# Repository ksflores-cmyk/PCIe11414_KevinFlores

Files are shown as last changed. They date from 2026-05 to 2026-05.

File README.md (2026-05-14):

# Proyecto Final de Electrónica 2 y Diseño Electrónico 1 - PCIe11414 NIC 

<div align="center">
  <em>Universidad del Istmo de Guatemala</em><br>
  <em>Facultad de Ingeniería</em><br>
  <em>Proyecto Final</em><br>
  <em>Electrónica 2 y Diseño Electrónico 1</em>

  <br><br>

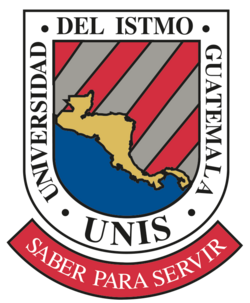
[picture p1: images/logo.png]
Logo UNIS
  
  
  <br><br>

  <em>Kevin Flores</em><br>
  <em>Mayo de 2026</em>
</div>

##  Descripción General
Este repositorio contiene el diseño a nivel de hardware de una tarjeta de red (NIC) con conexión PCIe. Desarrollado íntegramente en OrCAD, el proyecto documenta el proceso de ingeniería que incluye la selección de componentes, el diseño del esquemático y el layout de la PCB. Se prestó especial atención al enrutamiento de señales diferenciales y al cumplimiento de los estándares físicos que requiere el protocolo PCI Express.

##  Objetivos
* **Principal:** Diseñar a nivel de hardware (captura esquemática y layout de PCB) una Tarjeta de Interfaz de Red (NIC) y Hub basada en el switch PCI Express **PCI11414**, utilizando la suite de OrCAD y cumpliendo con los requerimientos técnicos del curso de Electrónica 2.
* **Específicos:**
  * Desarrollar el diagrama esquemático completo asegurando la interconexión entre el bus PCIe (Upstream x4), el switch PCI11414 y el transceptor Ethernet Gigabit (PHY) KSZ9131.
  * Implementar técnicas de diseño de placas de alta velocidad, incluyendo el ruteo de pares diferenciales y control de impedancia para el bus PCIe y las líneas de red.
  * Diseñar la red de distribución de energía (PDN) para adaptar los 12V de entrada a los voltajes de operación internos requeridos (5V, 3.3V, 2.5V y 1.1V).
  * Generar la documentación y los archivos de fabricación (Gerbers) correspondientes al diseño final.

##  Hardware y Componentes Utilizados
El diseño se basó en el esquemático de referencia de la tarjeta de evaluación EVB-PCI11414 de Microchip, utilizando componentes de montaje superficial (SMD) enfocados en telecomunicaciones de alta velocidad. A continuación, se detallan los componentes clave:

**Software de Diseño:**
* **Cadence OrCAD Capture:** Para la creación y jerarquización del diagrama esquemático.
    <br>
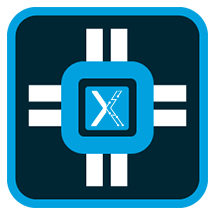
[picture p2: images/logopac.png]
Cadence OrCAD Capture
  
  <br><br>
* **Cadence Allegro PCB Editor:** Para el ruteo de pistas, manejo de capas y generación del layout.
    <br>
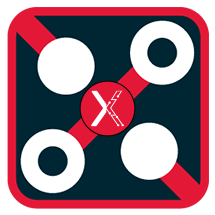
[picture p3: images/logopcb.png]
Cadence Allegro PCB Editor
  
  <br><br>

**Componentes Principales del Diseño:**
* **Switch PCIe Principal:** Microchip **PCI11414** (PCIe Switch con soporte para USB Host, Quad-UART y puerto Ethernet).
* **Controlador Ethernet (PHY):** Microchip **KSZ9131** (Transceptor Gigabit Ethernet 10/100/1000Base-T).
* **Interfaces de Bus PCIe:** * Conector tipo "Edge" PCI Express x4 (Upstream / conexión a la placa base).
  * Conector de ranura PCI Express x1 (Downstream).
* **Conector de Red:** Jack RJ45 modular con transformadores de aislamiento magnético integrados y LEDs indicadores.
* **Gestión de Energía:** Red de reguladores de voltaje tipo Buck y LDO (ej. Módulos PM8/LV2 y OKR-T) para reducir los 12V principales a rieles de 5V, 3.3V, 2.5V y 1.1V.
* **Sincronización (Relojes):** Cristal oscilador principal de 25 MHz (VXM7) y un Buffer de reloj de referencia PCIe de 2 canales (Microchip ZL40262LDF1).
* **Memoria de Configuración:** Memoria EEPROM I2C (AT24C64D) para almacenar la configuración de inicio del sistema.

## Diagrama de Bloques

A continuación se presenta la arquitectura general y el flujo de datos del diseño:

<div align="center">
<br>
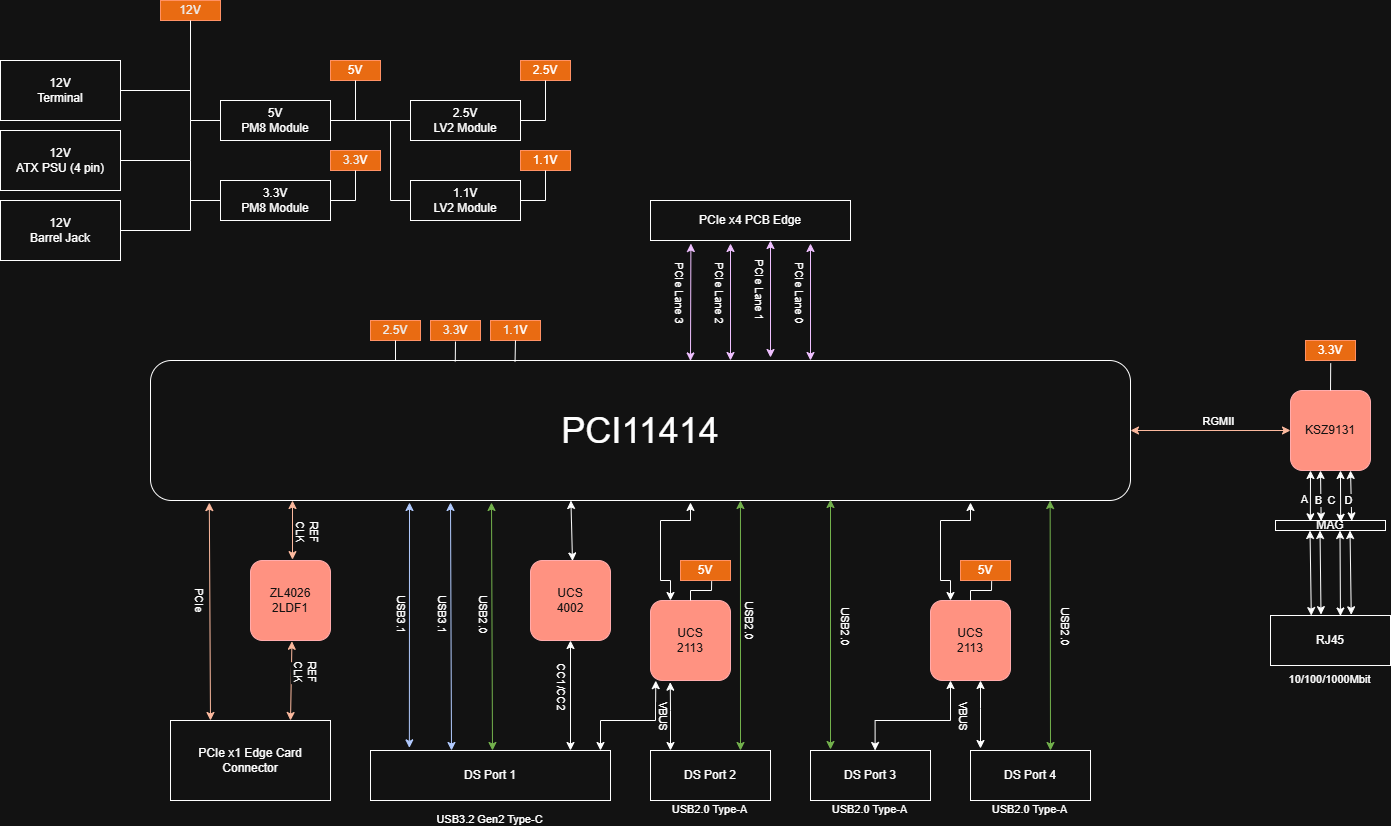
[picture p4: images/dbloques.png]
Diagrama de Bloques del Switch PCIe a NVMe
  
  
  <br>
  <em>Diagrama de bloques del sistema.</em>
</div>

##  Esquemáticos y Diseño
La arquitectura del circuito se fundamenta en el switch **PCI11414**, que funciona como el nodo central de comunicación. Este integrado gestiona el flujo de datos entre la interfaz **PCIe x4** de entrada (Upstream) y los diversos periféricos, incluyendo el controlador Ethernet **KSZ9131** y una ranura de expansión **PCIe x1** (Downstream).

Para garantizar la estabilidad del sistema, se implementó una arquitectura de potencia de cuatro etapas que regula la entrada principal de **12V** hacia los rieles de **5V**, **3.3V**, **2.5V** y **1.1V** requeridos por los distintos núcleos del switch y el PHY de red. La integridad de la señal se mantiene mediante un buffer de reloj especializado y un cristal de **25 MHz** para la sincronización de datos.
<div align="center">
<br><br>
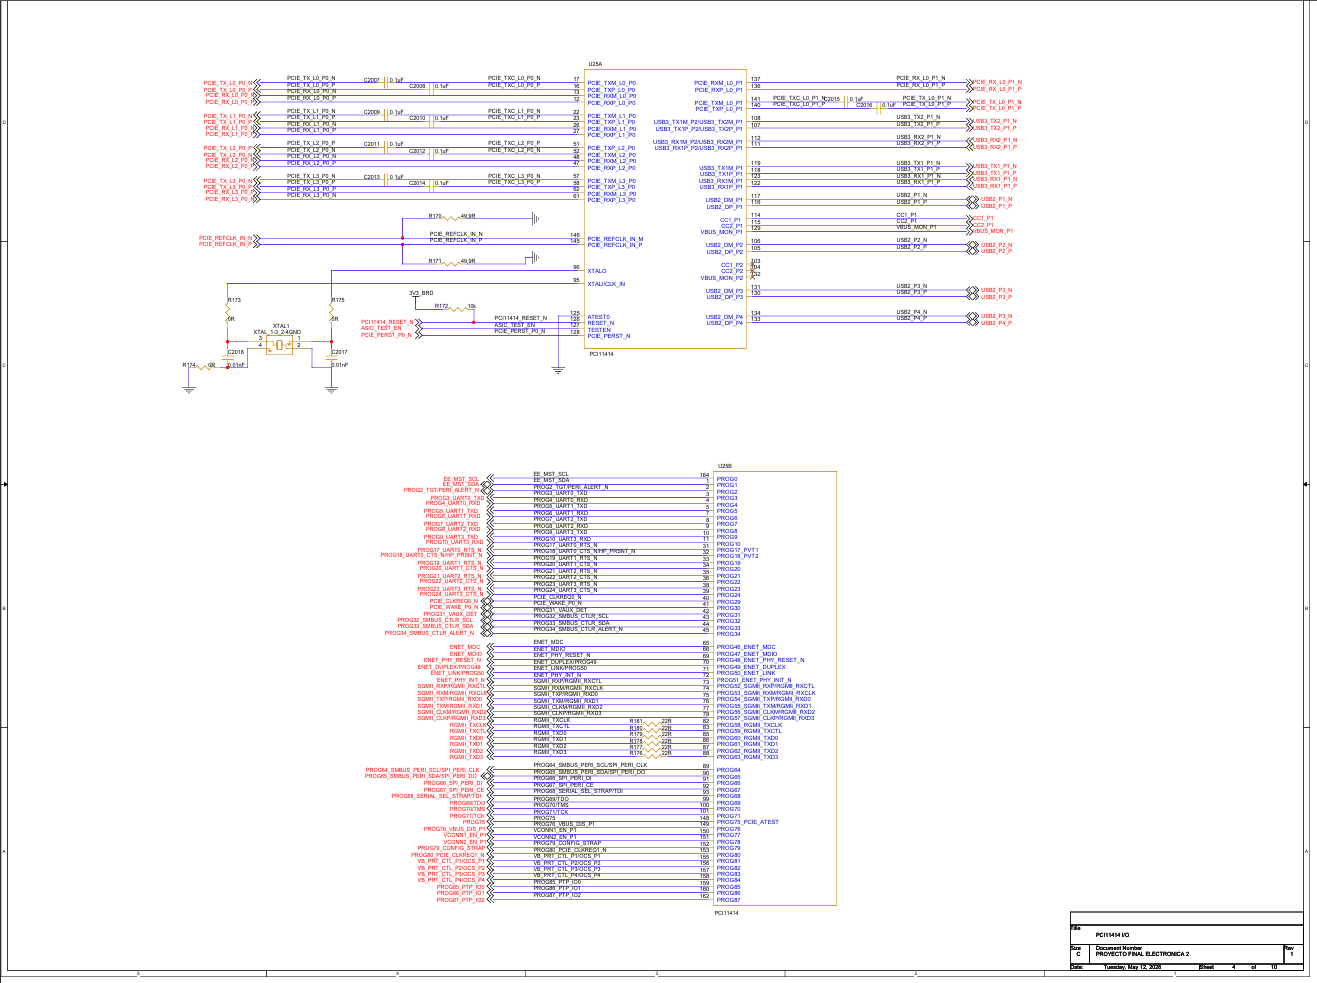
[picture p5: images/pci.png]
Esquemático de Conexiones - PCI11414
  
  
  <br>
  <em>Diagrama esquemático de conexiones para el IC PCI11414.</em>

<br><br>
> **Nota:** Todos los archivos técnicos, incluyendo las imágenes del esquemático completo y las capturas del diseño de la PCB, se encuentran disponibles en la carpeta `/[ESQUEMATICO]` de este repositorio.
 </div> 

##  Autor
Kevin Sebastian Flores López - Estudiante de Ingeniería Electrónica y Telecomunicaciones - https://github.com/ksflores-cmyk

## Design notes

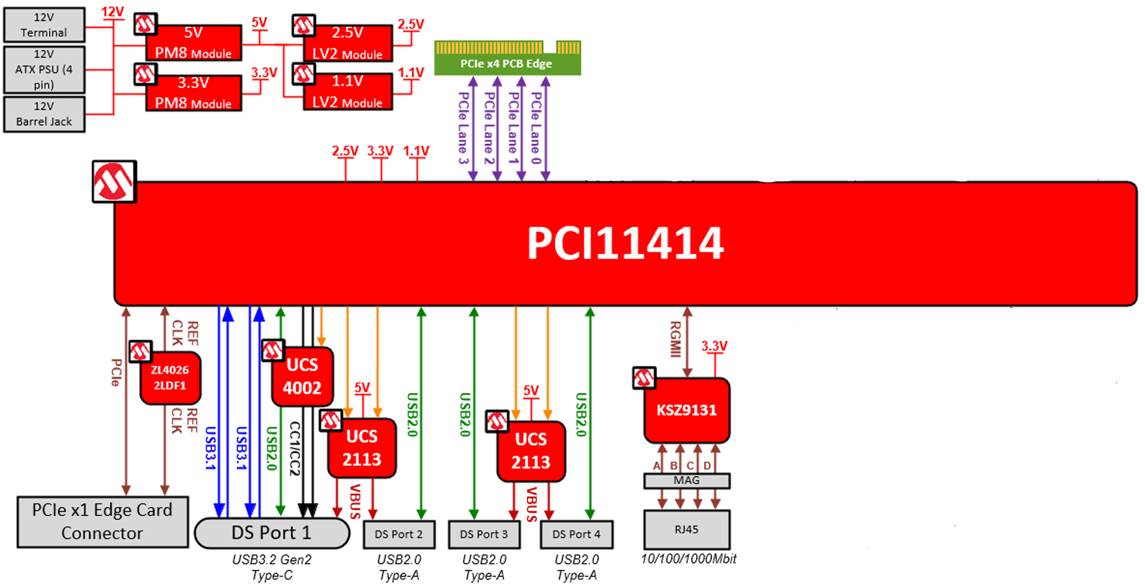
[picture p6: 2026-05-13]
images/Diagrama de Bloques.png

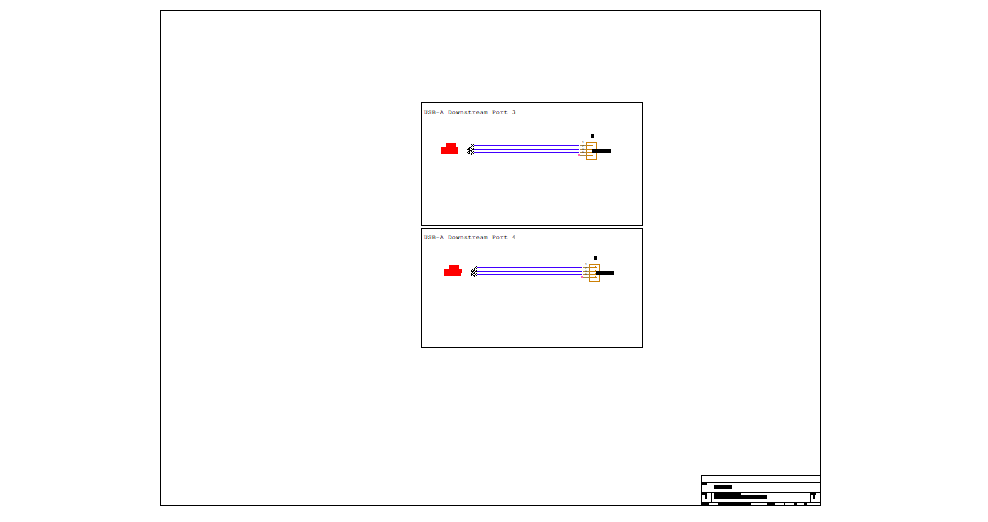
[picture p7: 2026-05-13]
DSN & BRD/PCI11414_KEVIN FLORES.png

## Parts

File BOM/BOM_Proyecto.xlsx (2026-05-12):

Capacitores (Desacople, Filtrado y Bulk) |  |  |  | Resistencias |  |  |  | Circuito Integrado
Categoría | Referencia | Valor | Voltaje / Encapsulado (Contexto) | Categoría | Referencia | Valor | Tolerancia / Observaciones | Categoría | Número de Parte / Referencia | Descripción | Cantidad
Capacitor Cerámico | C22, C31 | 4.7uF | 0603 (Desacople de potencia Ethernet PHY) | Resistencia | R221 | 43k | 1% (Divisor de voltaje VBUS) | Circuito Integrado | PCI11414 | Switch PCIe con host USB xHCI / Quad-UART / Ethernet | 1
Capacitor Cerámico | C23, C24, C40 | 0.1uF | 0603 (Desacople general) | Resistencia | R222 | 49.9k | 1% (Precisión para monitoreo) | Circuito Integrado | KSZ9131 | Ethernet PHY 10/100/1000MBit | 1
Capacitor Cerámico | C42 | 22uF | 10V / 0603 | Resistencia | R25, R88, R169 | 100k | Pull-up / Pull-down general | Circuito Integrado | ZL40262LDF1 | Buffer de Reloj PCIe (2 canales) | 1
Capacitor Cerámico | C200 | 47uF | 6.3V (Filtrado PMOS) | Resistencia | R149, R151, R233 | 10k | Configuración de pines (Strapping) | Circuito Integrado | AT24C64D | Memoria EEPROM I2C | 1
Capacitor Cerámico | C189, C191 | 22uF / 0.1uF | Filtrado entrada 12V PCIe | Resistencia | R40 | 20R | Resistencia en serie | Circuito Integrado | MAX3161 | Transceptor UART Multiprotocolo (RS-232/RS-485) | 4
Capacitor Cerámico | C83, C80 | 1000pF | Desacople de alta frecuencia (PCI11414) | Resistencia | R179, R165 | 330R | Limitadora de corriente para LEDs | Circuito Integrado | UCS4002 | Protección USB Type-C y fuente VCONN | 1
 |  |  |  | Resistencia | R6, R11, R7 | 22R | Terminación en serie para señales RGMII (Ethernet) | Circuito Integrado | UCS2113 | Switch de potencia para puertos USB | 2
 |  |  |  |  |  |  |  | Reloj / Oscilador | VXM7-9013-25M0000000 | Cristal de 25MHz | 1
 |  |  |  |  |  |  |  | Módulo de Potencia | OKR-T/6-W12 | Regulador DC-DC 12V a 5V/3.3V (6A) | -
 |  |  |  |  |  |  |  | Módulo de Potencia | PM-LV2 3.6V 3A | Regulador DC-DC para 2.5V y 1.1V | -
 |  |  |  |  |  |  |  | Módulo de Potencia | ADM00987 | Regulador LDO / Controlador | 1
 |  |  |  |  |  |  |  | Conector (Borde) | PCIe x4 PCB Edge | Conector de borde PCIe Upstream (hacia tarjeta madre) | 1
 |  |  |  |  |  |  |  | Conector (Slot) | PCIe x1 Edge Card | Slot PCIe Downstream | 1
 |  |  |  |  |  |  |  | Conector (Red) | RJ45 | Puerto Ethernet Gigabit (con magnéticos) | 1
 |  |  |  |  |  |  |  | Conector (USB) | USB Type-C | Puerto USB 3.2 Gen2 Downstream | 1
 |  |  |  |  |  |  |  | Conector (USB) | USB Type-A | Puerto USB 2.0 Downstream | 3
 |  |  |  |  |  |  |  | Conector (Serial) | DE-9 (Macho) | Conector DB9 para puerto serial RS-232 | 4
 |  |  |  |  |  |  |  | Conector (Serial) | Header RS-485 | Conector de pines para RS-485 | 4
 |  |  |  |  |  |  |  | Conector (Poder) | 12V Terminal | Bloque de terminales 12V | 1
 |  |  |  |  |  |  |  | Conector (Poder) | ATX PSU (4 pin) | Conector de fuente de poder ATX 12V | 1
 |  |  |  |  |  |  |  | Conector (Poder) | 12V Barrel Jack | Conector cilíndrico estándar 12V | 1

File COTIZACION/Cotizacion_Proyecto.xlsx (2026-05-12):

Cotización y BOM Consolidado |  |  |  |  |  | Costos de Manufactura, Ensamble y Envío
Categoría | Número de Parte / Ref. | Descripción | Cant. | Precio Unit. Est. (USD) | Subtotal Est. (USD) | Concepto de JLCPCB | Descripción Técnica | Subtotal Estimado (USD)
Integrado (Switch PCIe) | PCI11414 | Switch PCIe con host USB xHCI / Quad-UART / Ethernet | 1 | $30.56 | $30.56 | Fabricación PCB Bareboard | 5 unidades. 4 Capas (Impedancia controlada). Acabado ENIG + Gold Fingers + Biselado (Edge connector 45°). Tamaño est. 100x100mm. | ~$45.00
Integrado (Red) | KSZ9131RNXC | Ethernet PHY 10/100/1000MBit | 1 | $4.14 | $4.14 | Tarifa de Setup PCBA | Cargo fijo de JLCPCB por preparar la máquina Pick & Place (Setup fee + Stencil). | ~$10.00
Integrado (Reloj) | ZL40262LDF1 | Buffer de Reloj PCIe (2 canales) | 1 | $3.50 | $3.50 | Mano de obra Ensamble (SMT) | Costo por punto de soldadura para ensamblar 2 unidades. | ~$15.00
Integrado (Memoria) | AT24C64D | Memoria EEPROM I2C | 1 | $0.17 | $0.17 | Envío a Guatemala | DHL Express o FedEx (Esencial. Tarda aprox. 5-7 días hábiles a GT). | ~$40.00
Integrado (UART) | MAX3161 | Transceptor UART (RS-232/RS-485) | 4 | $4.50 | $18.00 | SUBTOTAL MANUFACTURA |  | ~$110.00
Integrado (Prot. USB) | UCS4002 | Protección USB Type-C y fuente VCONN | 1 | $1.60 | $1.60
Integrado (Switch USB) | UCS2113-1C-V/G4 | Switch de potencia para puertos USB | 2 | $1.21 | $2.42
Reloj / Oscilador | VXM7-9013-25M... | Cristal de 25MHz | 1 | $0.50 | $0.50
Módulo DC-DC | OKR-T/6-W12 | Regulador 12V a 5V/3.3V (6A) | 1 | $5.00 | $5.00
Módulo DC-DC | PM-LV2 3.6V 3A | Regulador para 2.5V y 1.1V | 1 | $4.00 | $4.00
Regulador LDO | ADM00987 | Regulador / Controlador | 1 | $1.00 | $1.00
Conector (Upstream) | PCIe x4 PCB Edge | Conector de borde PCIe (Oro en PCB) | 1 | N/A (PCB) | $0.00
Conector (Downstream) | PCIe x1 Edge Card | Slot PCIe Hembra (SMT o THT) | 1 | $1.50 | $1.50
Conector (Red) | RJ45 | Puerto Ethernet Gigabit con magnéticos | 1 | $2.00 | $2.00
Conector (USB) | USB Type-C | Puerto USB 3.2 Gen2 | 1 | $0.80 | $0.80
Conector (USB) | USB Type-A | Puerto USB 2.0 | 3 | $0.40 | $1.20
Conector (Serial) | DE-9 (Macho) | Conector DB9 RS-232 | 4 | $0.60 | $2.40
Conector (Poder/Extra) | Headers / Terminales | RS-485, Jack 12V, ATX 4-pin, Terminal block | Lote | $3.00 | $3.00
Pasivos (SMD) | Varios | Capacitores, Resistencias, Ferritas, LEDs | Lote | $5.00 | $5.00
TOTAL ESTIMADO |  |  |  |  | ~$86.79 USD

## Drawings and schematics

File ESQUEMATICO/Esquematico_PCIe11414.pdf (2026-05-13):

5

4

3

2

1

D D

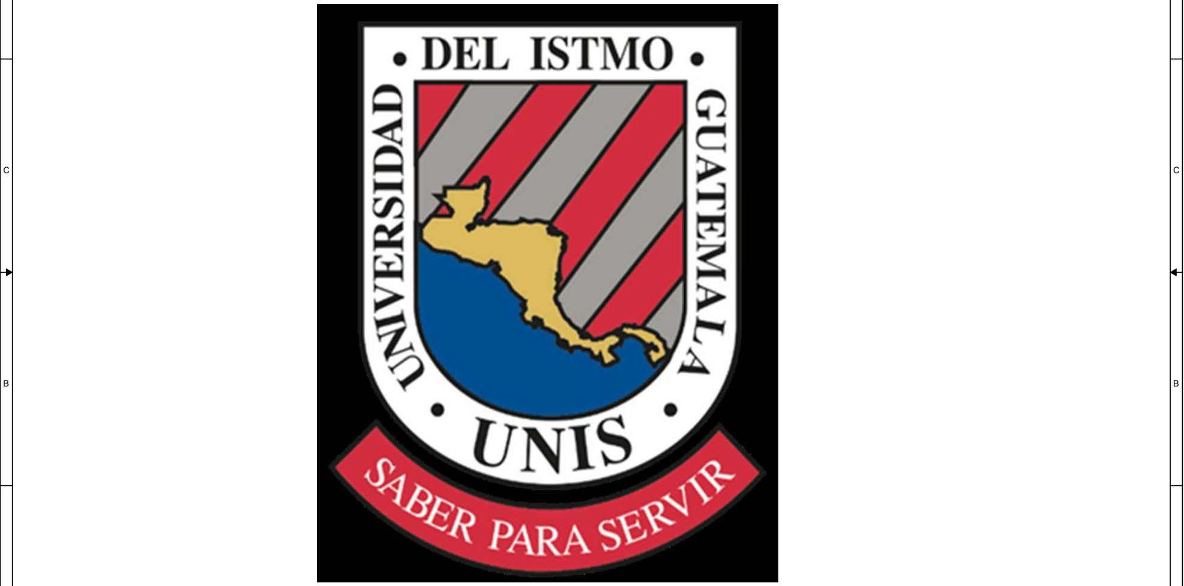
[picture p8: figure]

A A

# ABRIL DE 2026

# ELECTRONICA 2 Y DISENO ELECTRICO 1

# UNIVERSIDAD DEL ISTMO DE GUATEMALA FACULTAD DE INGENIERIA

# PROYECTO FINAL - PCIe NIC 11414

# KEVIN SEBASTIAN FLORES LOPEZ

D D

C C

B B

A A

# UPSTREAM PORT

# DOWNSTREAM SWITCH PORT

I/O

PG. #

# PCIe NVMe SWITCH - TABLE OF CONTENTS

5

# POWER

4

# BOARD POWER & RESETS

3

6

2

# SECTION

8

9

# ETHERNET

DOWNSTREAM PORTS | 7

# ETHERNET POWER

D D

# 12V - 5V Regulator

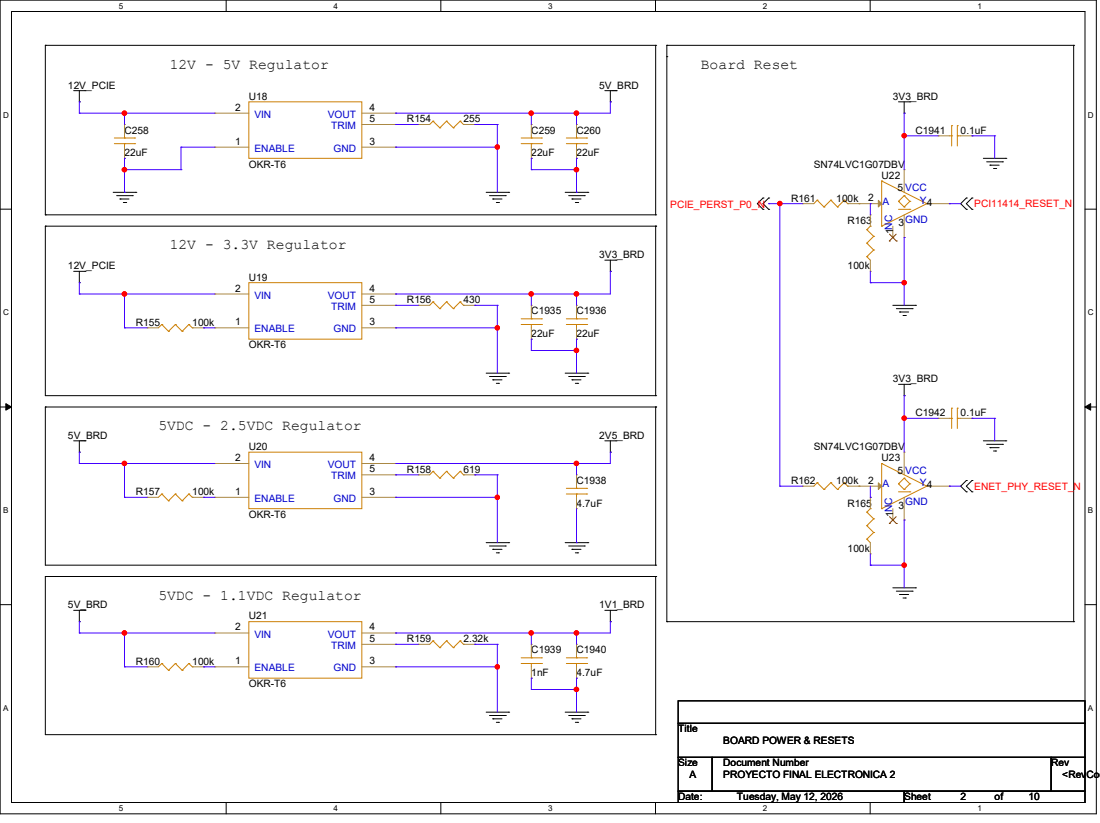
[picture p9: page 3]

### 2V5_BRD

### 3V3_BRD

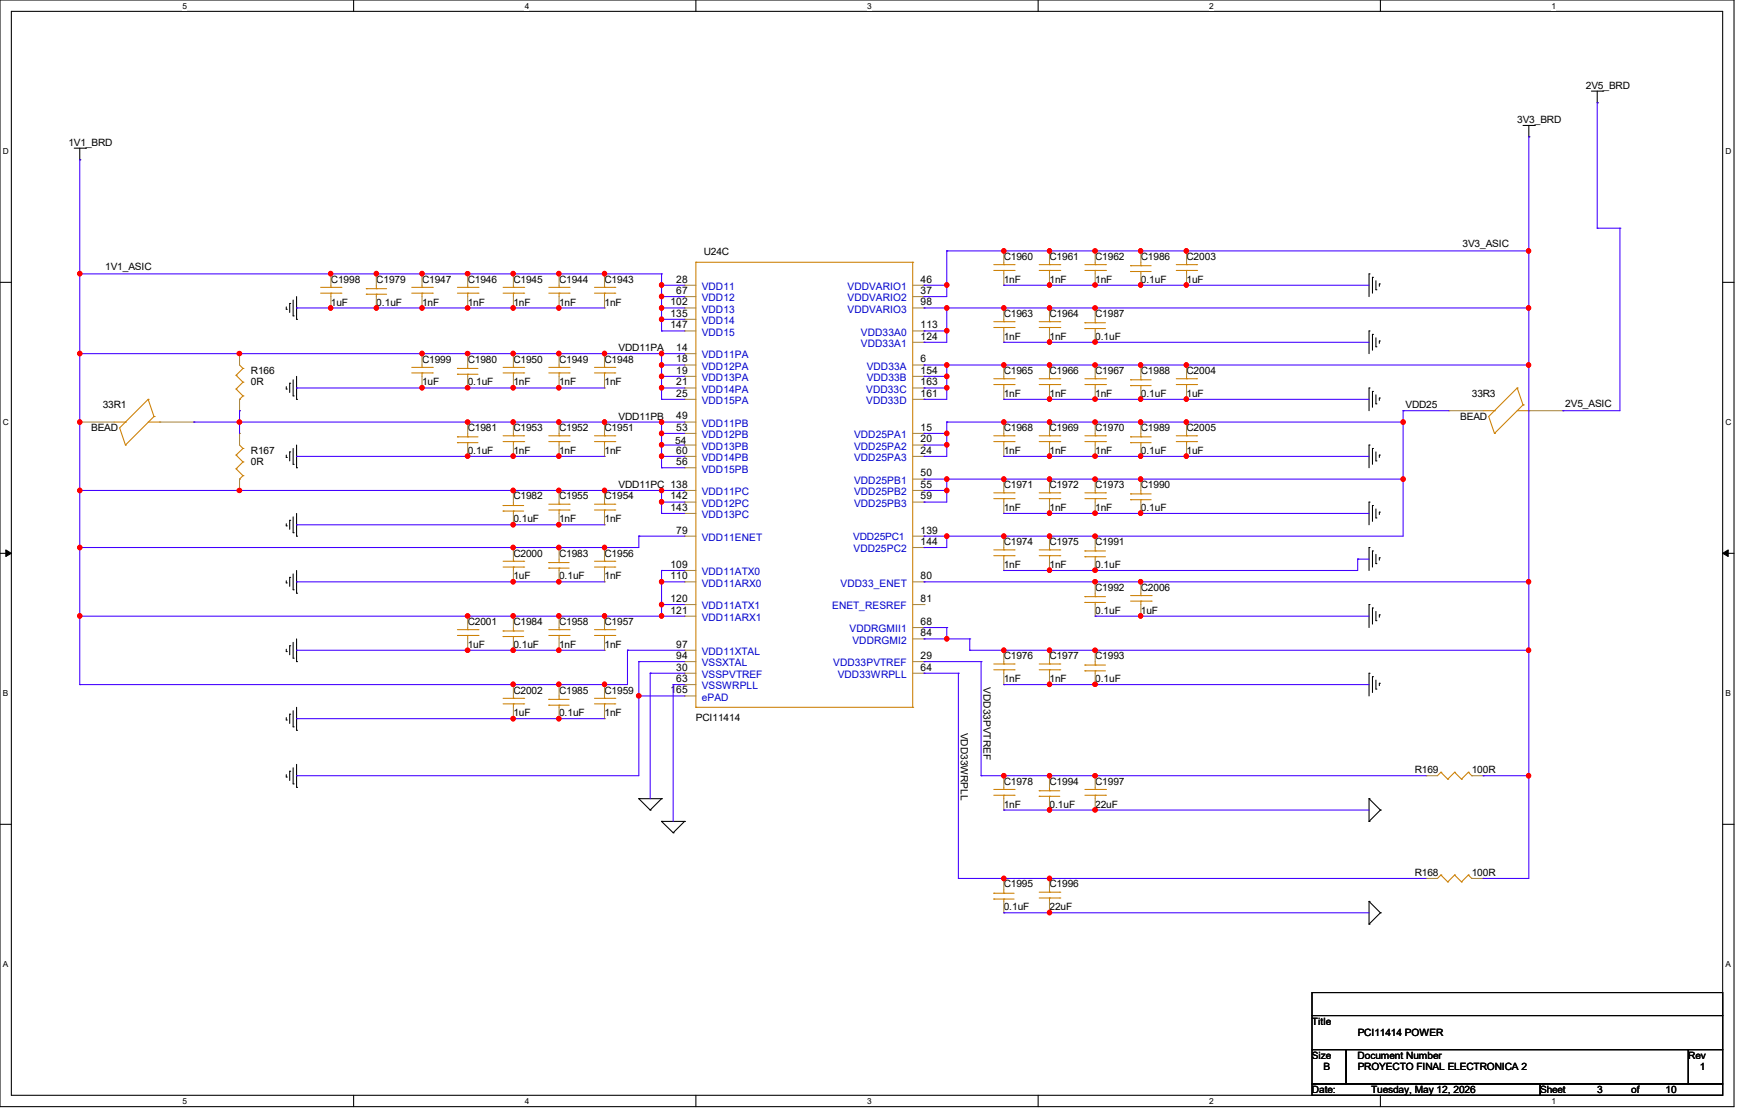
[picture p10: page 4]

# USB2_P4_P USB2_P1_N

# USB2_P1_P USB2_P3_P

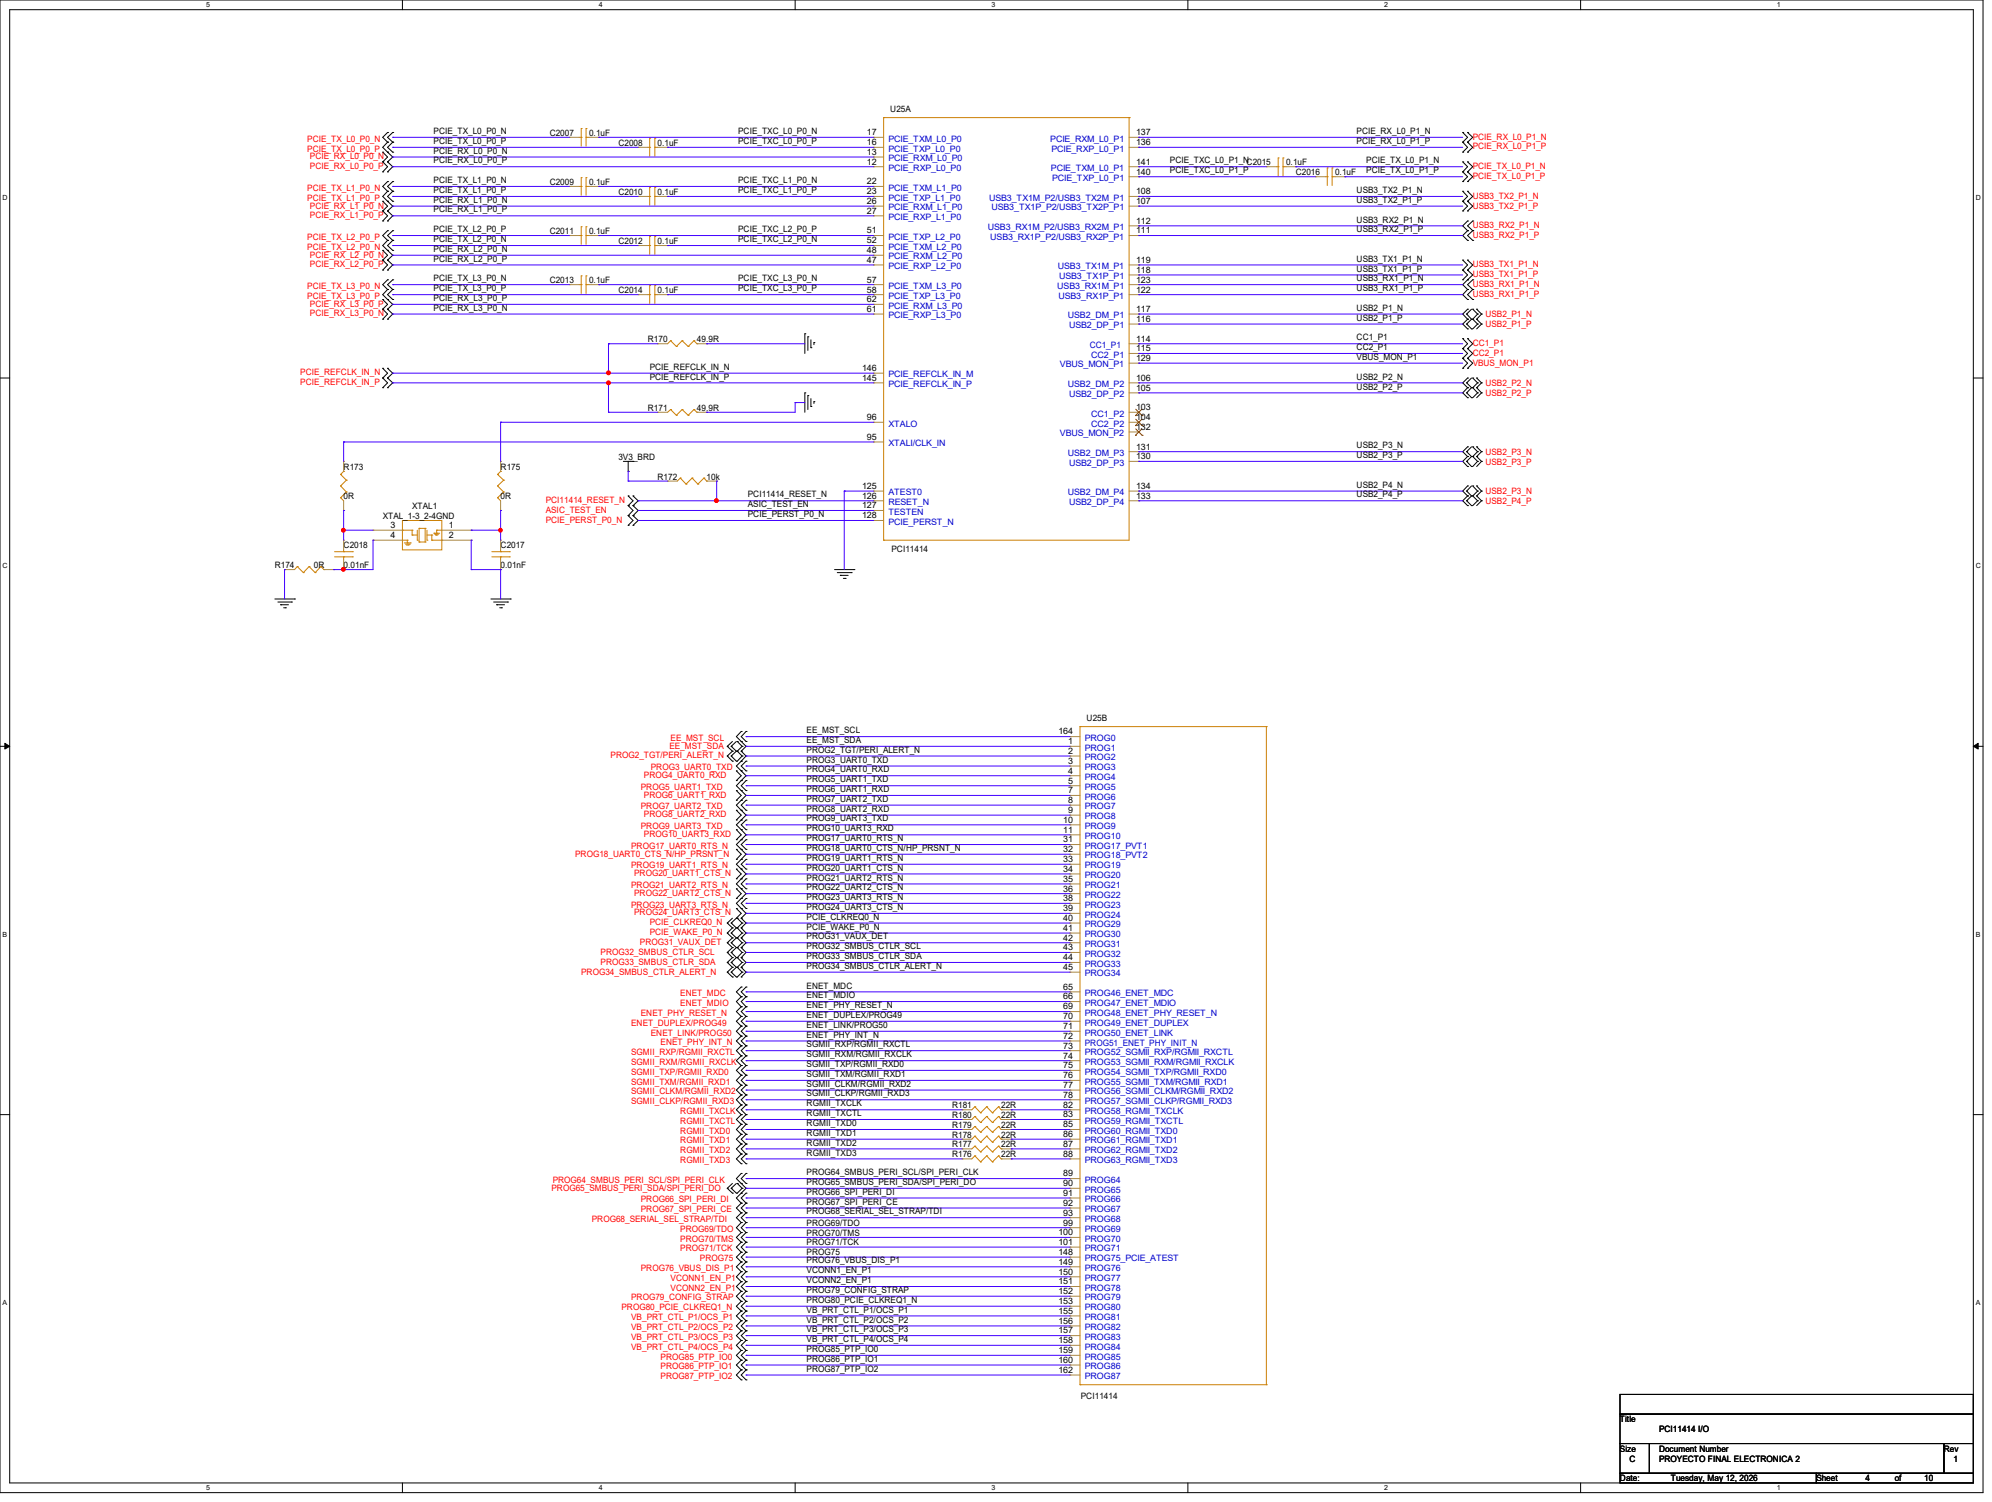
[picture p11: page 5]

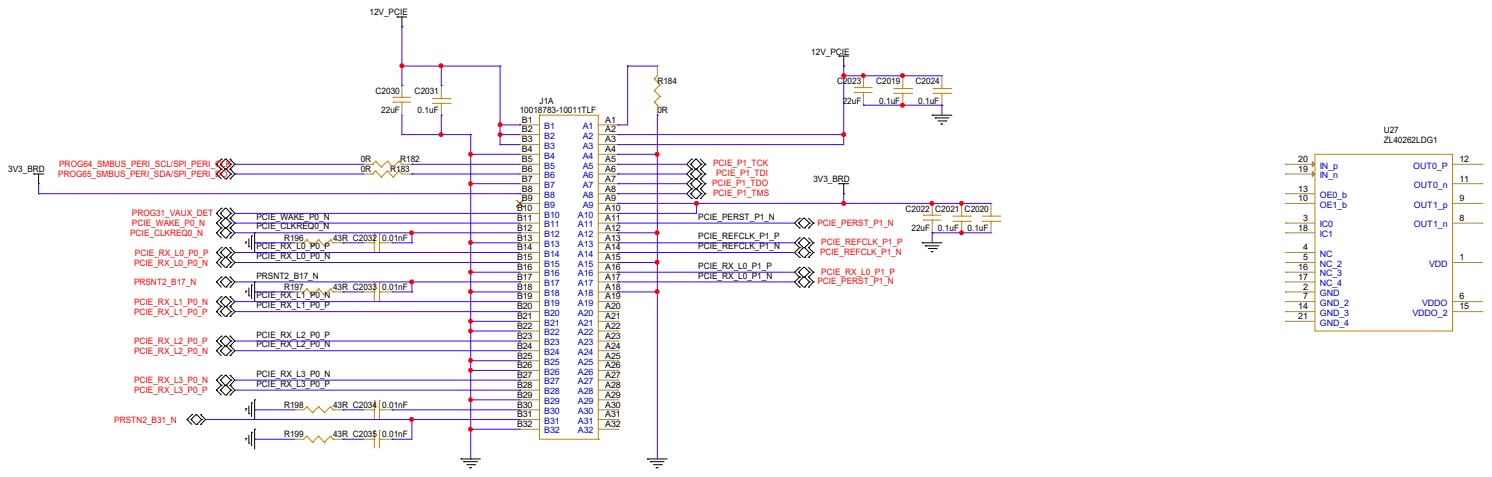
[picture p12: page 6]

# UCS2114 Power Switch For Port 3 & Port 4 3V3_BRD

### 5V_BRD

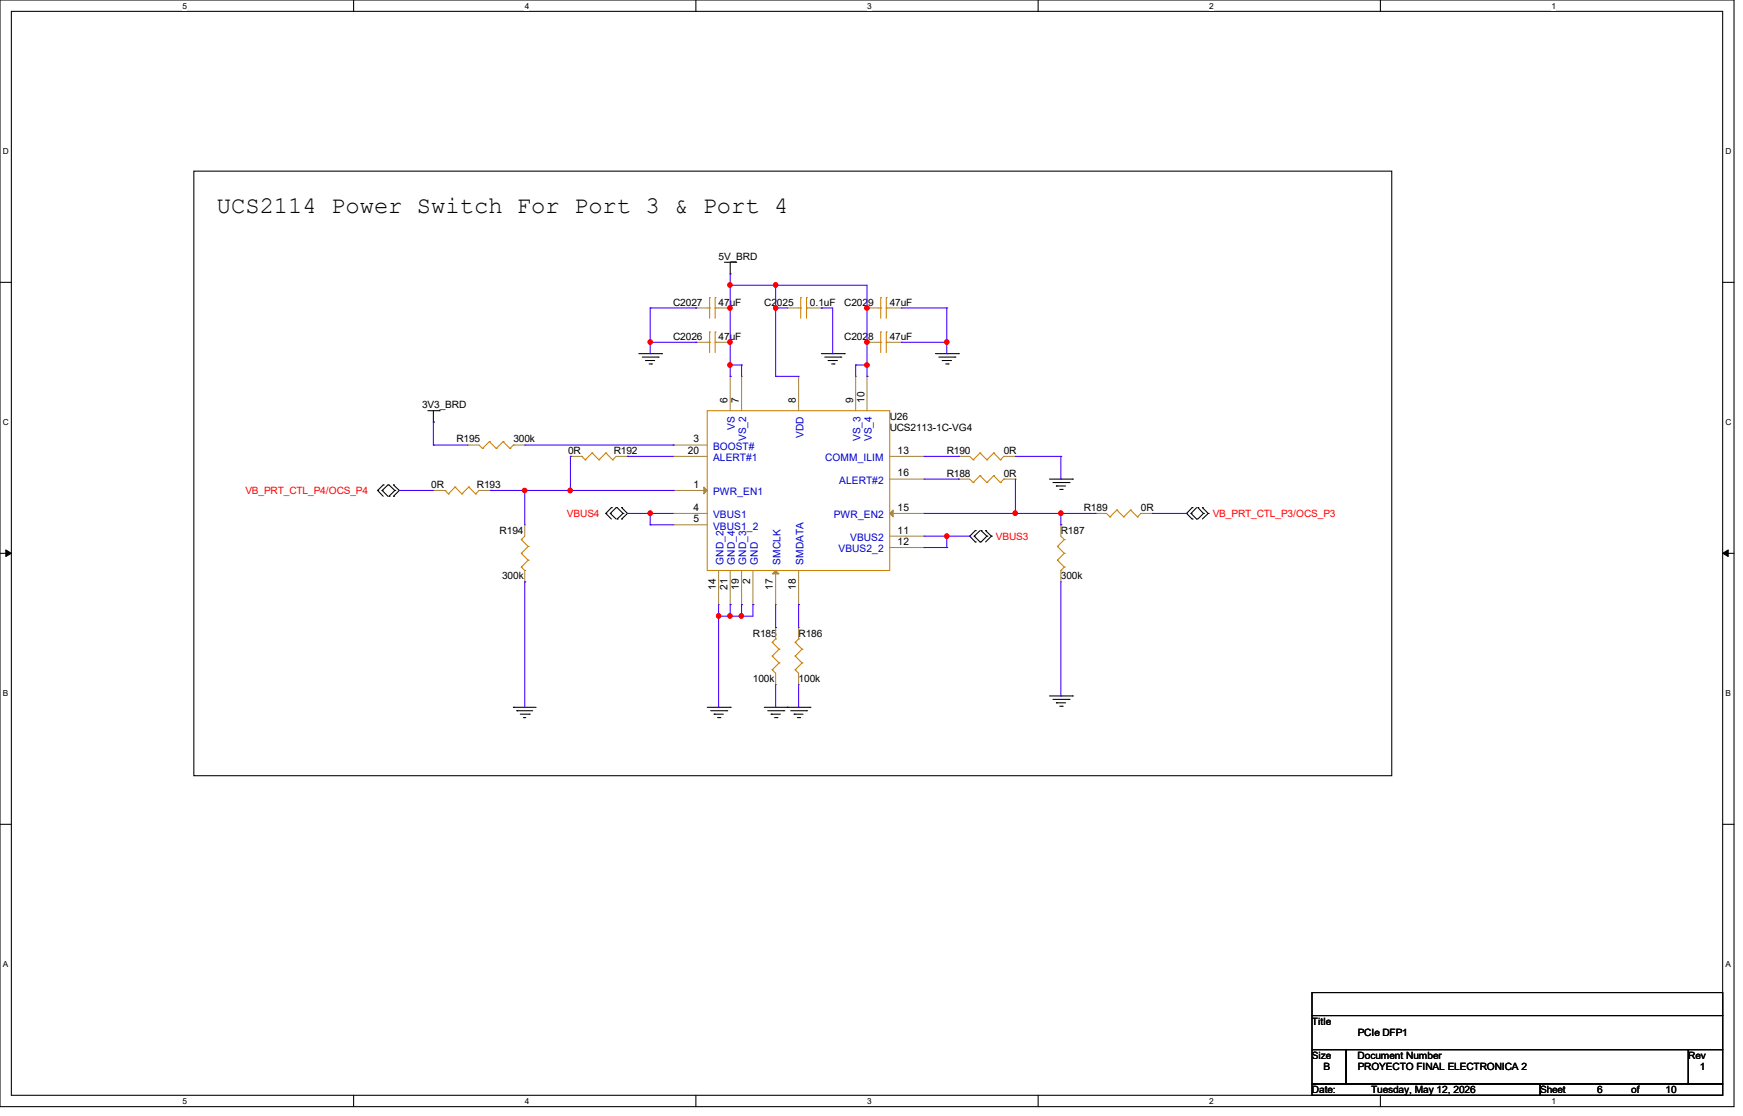
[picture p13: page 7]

9 VS_4 10 VBUS2 11 VBUS2_2 12 COMM_ILIM 13 GND_2 14 PWR_EN2 15 ALERT#2 16 SMCLK 17 SMDATA 18 GND_3 19 ALERT#1 20 GND_4 21

# USB-A Downstream Port 3

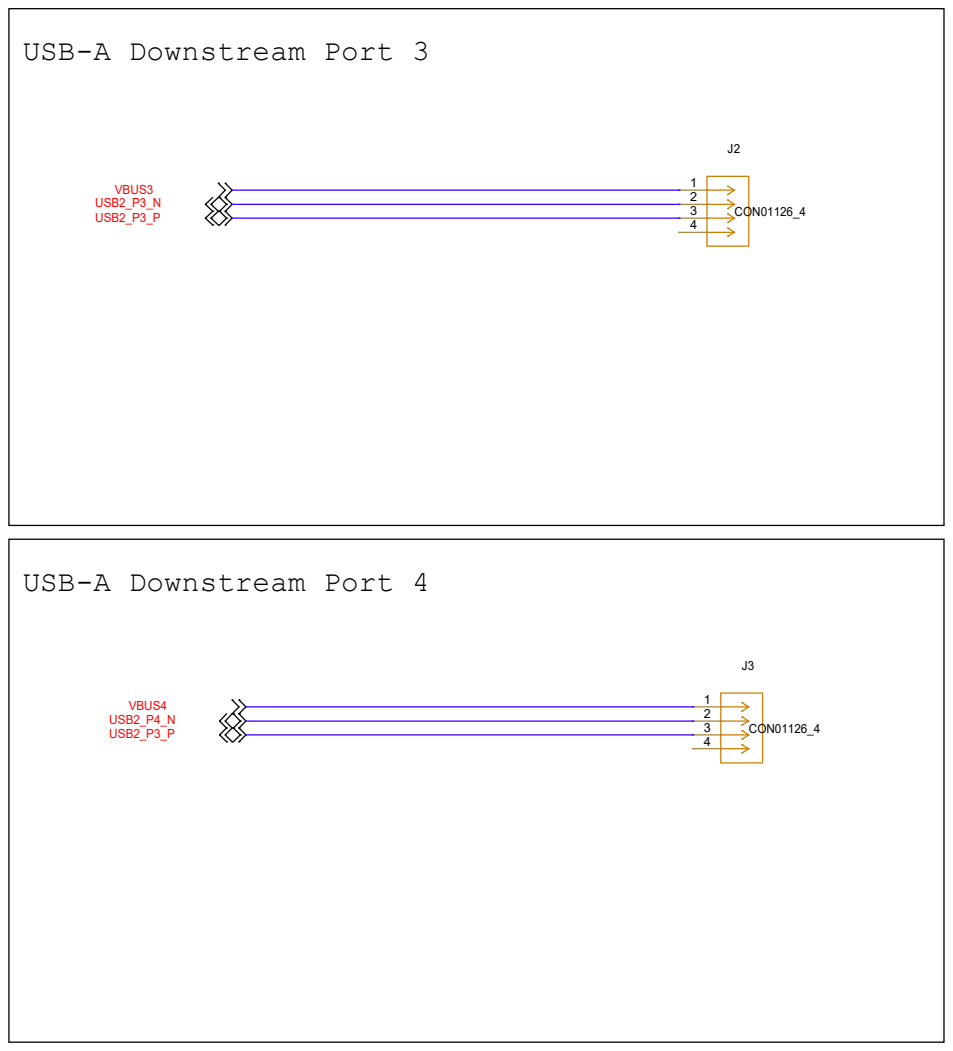
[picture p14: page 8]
VBUS3 VBUS4 USB2_P3_N USB2_P3_P USB2_P4_N; USB2_P3_P; Title Size; Document Number; Rev Date:; Sheet; of PROYECTO FINAL ELECTRONICA 2; 1 USB PORTS C; Tuesday, May 12, 2026; 10 Title Size; J3CON01126_4; J2CON01126_4

USB-A Downstream Port 4

D D

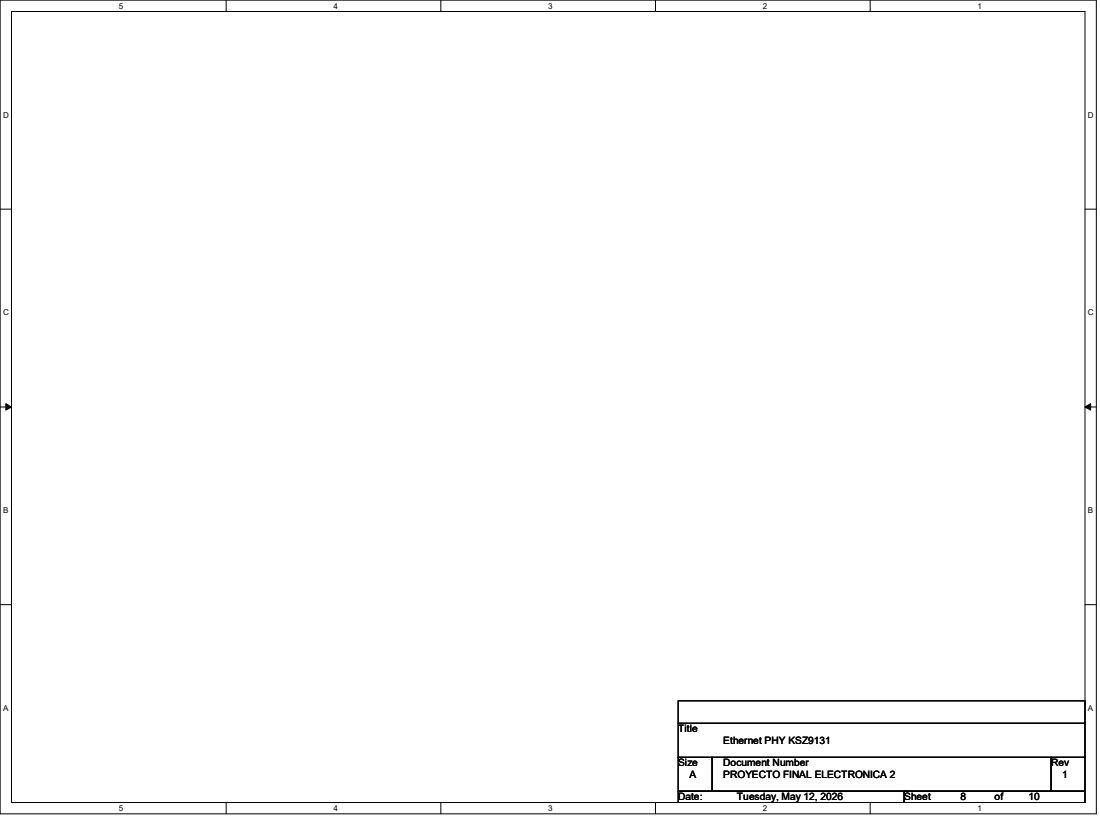
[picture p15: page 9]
A A Title; Size; Document Number; Rev; Date:; Sheet; PROYECTO FINAL ELECTRONICA 2; Ethernet PHY KSZ9131; Tuesday, May 12, 2026; Title

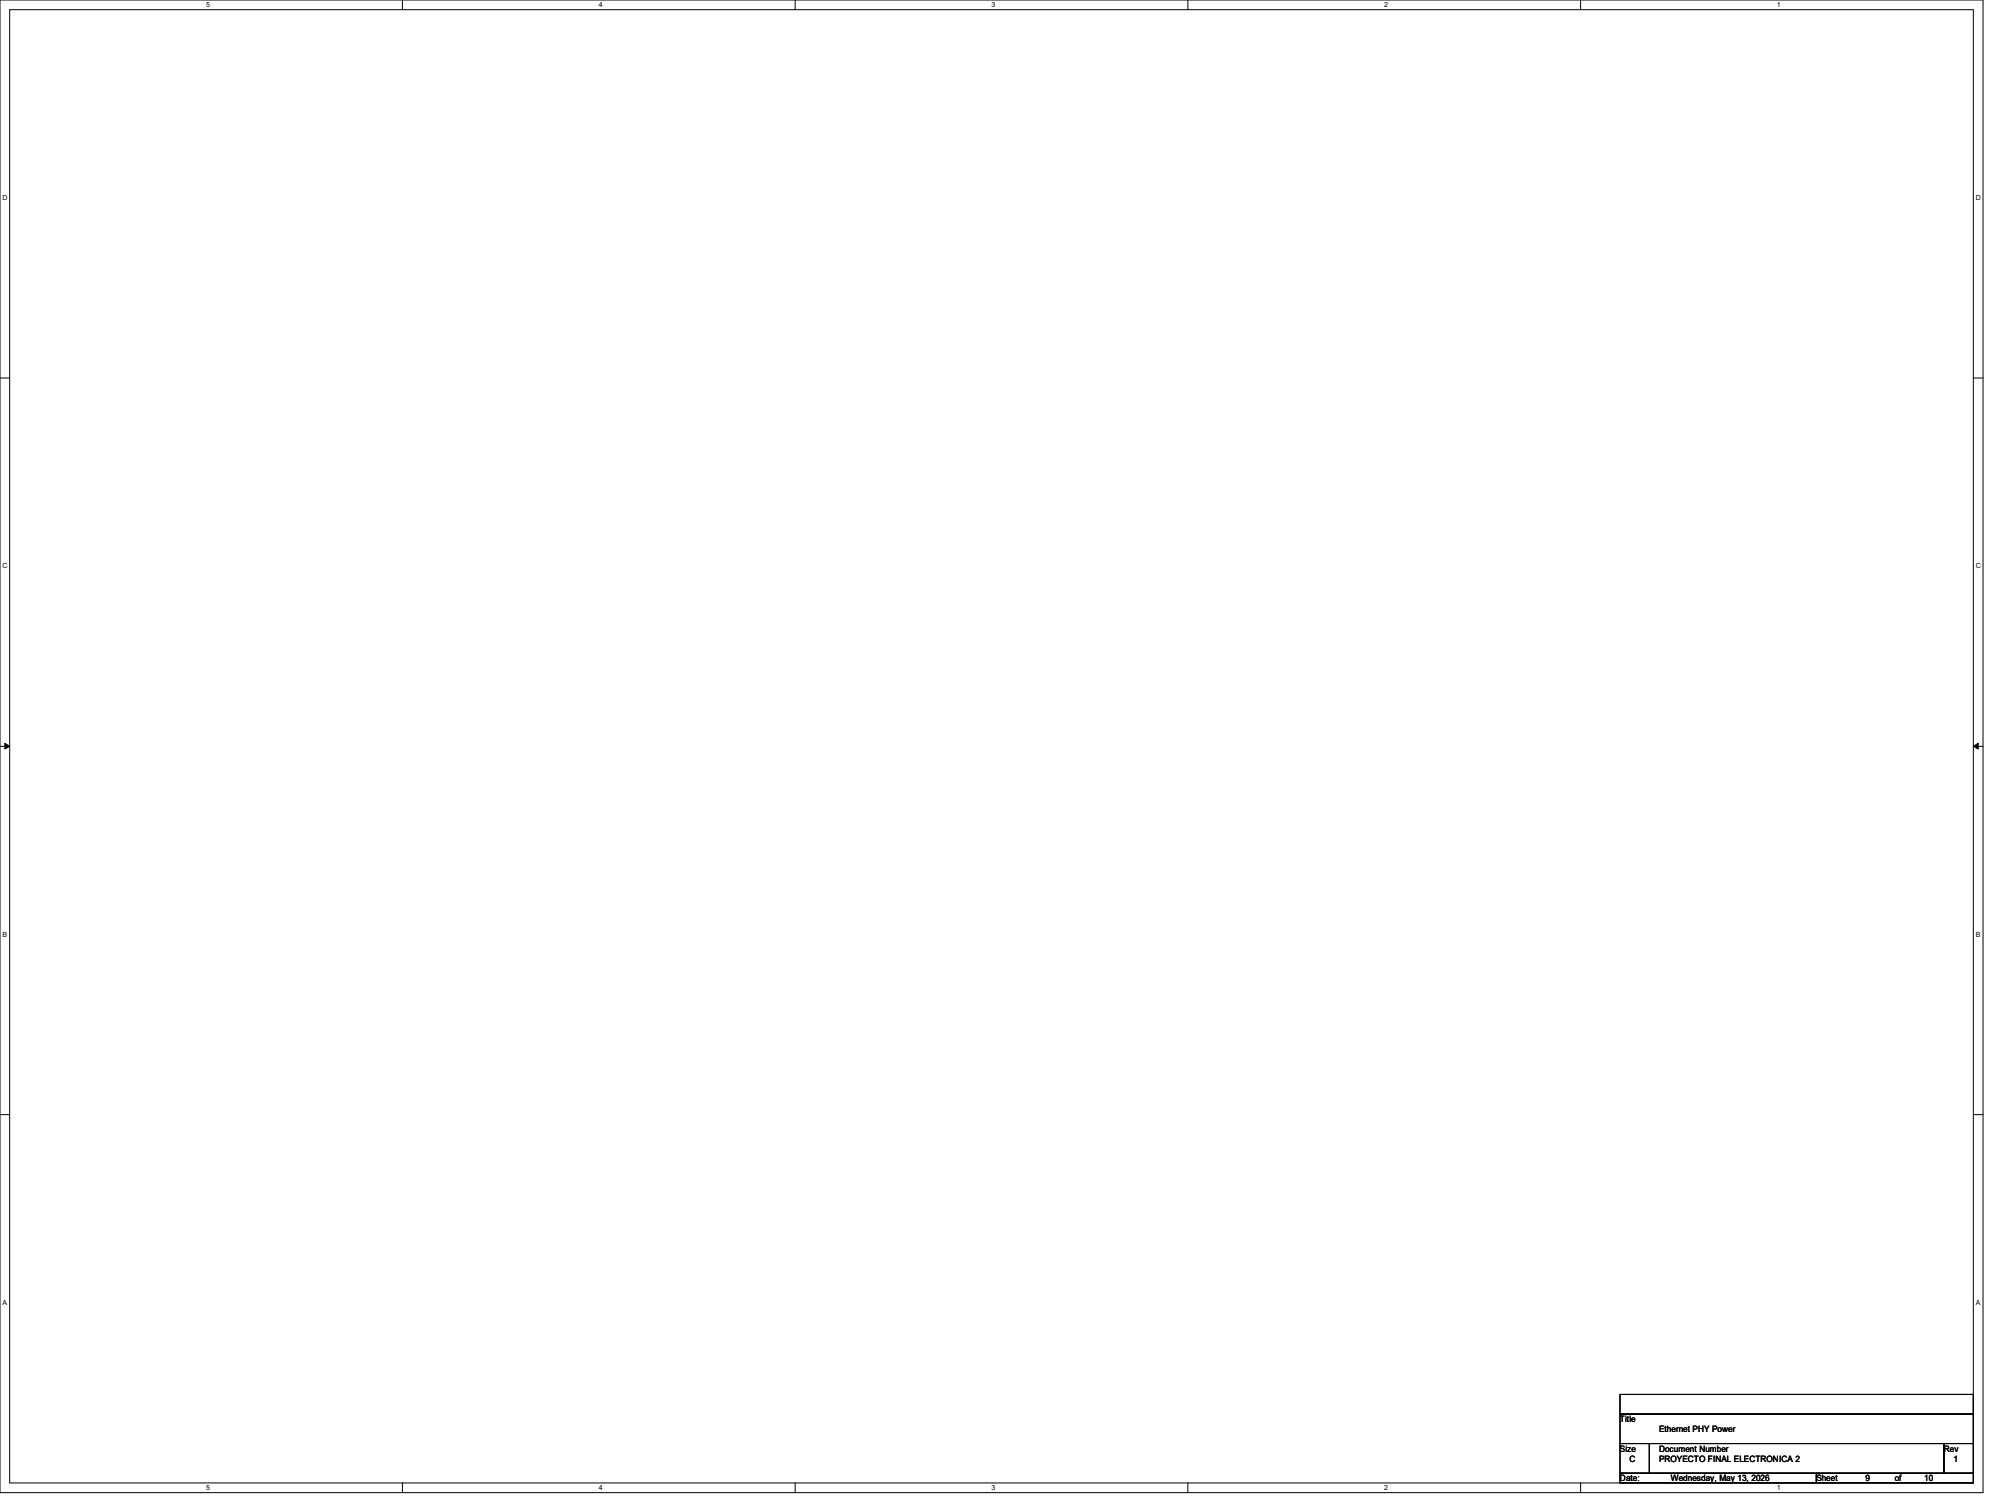
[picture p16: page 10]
A Title Size; Document Number; Rev Date:; Sheet; of PROYECTO FINAL ELECTRONICA 2; 1 Ethernet PHY Power C; Wednesday, May 13, 2026; 10 Title Size
